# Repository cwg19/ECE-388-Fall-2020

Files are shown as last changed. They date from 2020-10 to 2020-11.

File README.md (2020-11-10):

# Function Generator
## UMassD ECE 388 Embedded System Design

### Project Scope
Simple Function gnerator
* produces sinusoid, square, and triangle waves
* Adjustable frequency up to 1MHz
* Adjustable gain between +/- ~10V
* Adjustable phase
* Rotary encoder w/ push button to select setting and change value
* Keypad to enter value
* LCD display

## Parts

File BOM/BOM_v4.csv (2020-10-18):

Qty | Value | Device | Package | Tolerance | Rating | Parts | Description | LCSC Price 1 | LCSC Price 10 | LCSC Pricee 100 | LCSC Price 1000 | LCSC PN | LCSC Link | Digikey Price | Digikey Link
3 | 6.2V | ZENER-DIODESOD80C | SOD80C | 2V | 6.2V 500mW 3uA @ 4V | D1, D2, D3 | Z-Diode |  |  | 0.15439 | 0.03613212 | C282536 | https://lcsc.com/product-detail/Zener-Diodes_Nexperia-BZV55-B6V2-115_C282536.html
1 | 10nF | C-EUC0805 | C0805 | 10% | 500V | C20 | CAPACITOR, European symbol |  |  | 0.16748 | 0.1233 | C309038 | https://lcsc.com/product-detail/Multilayer-Ceramic-Capacitors-MLCC-SMD-SMT_CCTC-TCC0805X7R103K501DTS_C309038.html
15 | 100nF | C-EUC0805 | C0805 | 10% | 250V | C1, C2, C3, C4, C5, C6, C7, C8, C9, C10, C11, C12, C13, C14, C21 | CAPACITOR, European symbol |  |  | 0.08029 | 0.183533 | C710458 | https://lcsc.com/product-detail/Multilayer-Ceramic-Capacitors-MLCC-SMD-SMT_HUI-JU-NM0805B104K251CEDN_C710458.html
1 | 1 | R-EU_R0805 | R0805 | 5% | 0.125W | R1 | RESISTOR, European symbol |  |  | 0.001894 | 0.001449 | C104066 | https://lcsc.com/product-detail/Chip-Resistor-Surface-Mount_1R-1R0-5_C104066.html
10 | 10k | R-EU_R0805 | R0805 | 1% | 0.125W | R2, R12, R13, R14, R15, R16, R17, R18, R19, R20 | RESISTOR, European symbol |  |  | 0.002477 | 0.001928 | C38522 | https://lcsc.com/product-detail/Chip-Resistor-Surface-Mount_UNI-ROYAL-Uniroyal-Elec-0805W8F1002T5E_C38522.html
2 | 10uF | C-EUC0805 | C0805 | 10% | 25V | C15, C16 | CAPACITOR, European symbol |  | 0.034545 | 0.029111 | 0.026285 | C40894 | https://lcsc.com/product-detail/Multilayer-Ceramic-Capacitors-MLCC-SMD-SMT_FH-Guangdong-Fenghua-Advanced-Tech-0805X106K250NT_C40894.html
1 | 16MHz | CRYSTALHC49UP | HC49UP | 20ppm | 20pF 30ohm | Q1 | CRYSTAL |  | 0.17467 | 0.129776 | 0.113286 | C259047 | https://lcsc.com/product-detail/SMD-Crystal-Resonators_ECEC-ZheJiang-E-ast-Crystal-Elec-C16000J119_C259047.html
1 | 1M | R-EU_R0805 | R0805 | 5% | 0.125W | R10 | RESISTOR, European symbol |  |  | 0.001495 | 0.001107 | C131391 | https://lcsc.com/product-detail/Chip-Resistor-Surface-Mount_FH-Guangdong-Fenghua-Advanced-Tech-RS-05K105JT_C131391.html
9 | 1k | R-EU_R0805 | R0805 | 5% | 0.125W | R3, R21, R22, R23, R24, R25, R26, R27, R30 | RESISTOR, European symbol |  |  | 0.001474 | 0.001095 | C25623 | https://lcsc.com/product-detail/Chip-Resistor-Surface-Mount_UNI-ROYAL-Uniroyal-Elec-0805W8J0102T5E_C25623.html
8 | 1.3k | R-EU_R0805 | R0805 | 1% | 0.125W | R4, R5, R6, R7, R8, R9, R31, R32 | RESISTOR, European symbol |  |  | 0.031326 | 0.022996 | C230658 | https://lcsc.com/product-detail/Chip-Resistor-Surface-Mount_PANASONIC-ERJ6ENF1300V_C230658.html
1 | 1uF | C-EUC0805 | C0805 | 10% | 50V | C17 | CAPACITOR, European symbol |  |  | 0.087535 | 0.2013519 | C282736 | https://lcsc.com/product-detail/Multilayer-Ceramic-Capacitors-MLCC-SMD-SMT_CCTC-TCC0805X7R105K500DTB_C282736.html
2 | 2.2uF | C-EUC0805 | C0805 | 10% | 25V | C18, C19 | CAPACITOR, European symbol |  |  | 0.083415 | 0.01916993 | C19110 | https://lcsc.com/product-detail/Multilayer-Ceramic-Capacitors-MLCC-SMD-SMT_SAMSUNG_CL21B225KAFNNNE_2-2uF-225-10-25V_C19110.html
2 | 22pF | C-EUC0805 | C0805 | 5% | 50V | C22, C23 | CAPACITOR, European symbol |  |  | 0.021236 | 0.02361 | C465168 | https://lcsc.com/product-detail/Multilayer-Ceramic-Capacitors-MLCC-SMD-SMT_Chinocera-HGC0805G0220J500NTGJ_C465168.html
1 | 25MHz | CRYSTALHC49UP | HC49UP | 30ppm | 20pF 50ohm | Q2 | CRYSTAL |  | 0.189734 | 0.14142 | 0.117488 | C111118 | https://lcsc.com/product-detail/SMD-Crystal-Resonators_TAE-Zhejiang-Abel-Elec-HC-49SM25MHz20pF30ppm_C111118.html
1 | 4.7uH | L-EUL0201 | L0201 | 20% | 800mA 312mohm | L1 | INDUCTOR, European symbol |  | 0.033768 | 0.0246 | 0.022917 | C63166 | https://lcsc.com/product-detail/Inductors-SMD_Sunlord-MPL2012S4R7MHT_C63166.html
1 | 68k | R-EU_R0805 | R0805 | 5% | 0.125W | R11 | RESISTOR, European symbol |  |  | 0.001395 | 0.001007 | C25641 | https://lcsc.com/product-detail/Chip-Resistor-Surface-Mount_UNI-ROYAL-Uniroyal-Elec-0805W8J0683T5E_C25641.html
1 |  | A1944-50 | A1944 |  |  | X1 | BNC CONNECTOR 50 Ohm |  |  |  |  |  |  | 11.76 | https://www.digikey.com/en/products/detail/amphenol-rf/112435/2628898
1 |  | AD9833 | MSOP10 |  |  | IC1 | LowPower Waveform Generator | 4.575 | 3.926667 | 3.808333 | 3.688333 | C9652 | https://lcsc.com/product-detail/Interface-Direct-Digital-Synthesis-DDS_Analog-Devices_AD9833BRMZ_Analog-Devices-ADI-LINEAR-AD9833BRMZ_C9652.html
1 |  | DCJ0202 | DCJ0202 |  |  | J1 | DC POWER JACK |  | 0.243966 | 0.177334 | 0.152834 | C111573 | https://lcsc.com/product-detail/AC-DC-Power-Plugs-Receptacles_SOFNG-DC005-T25_C111573.html
2 |  | LM318MX/NOPB | SOIC-8 |  |  | IC4, IC5 | OP AMP | 0.803333 | 0.581667 | 0.486617 | 0.46075 | C128749 | https://lcsc.com/product-detail/General-Purpose-Amplifiers_Texas-Instruments_LM318MX-NOPB_Texas-Instruments-Texas-Instruments-LM318MX-NOPB_C128749.html
1 |  | MAX9939AUB+ | 21-0061L |  |  | U2 | Programmable Gain Amplifier | 2.511667 | 2.16 | 2.031667 | 1.966667 | C143637 | https://lcsc.com/product-detail/Operational-Amplifiers_MAXIM_MAX9939AUB_MAX9939AUB_C143637.html
1 |  | MICROCHIP_ATMEGA328PB-AUMICROCHIP_ATMEGA328PB-AU_0_0 | MICROCHIP_ATMEGA328PB-AU_0 |  |  | U1 | ATmega328PB Summary Datasheet | 2.865 | 2.086667 | 1.8 | 1.705 | C194192 | https://lcsc.com/product-detail/ATMEL-AVR_Microchip-Tech-ATMEGA328PB-AN_C194192.html
1 |  | TLV61048DBVR | SOT95P280X145-6N |  |  | U3 |  |  |  |  |  |  |  | 1.12 | https://www.digikey.com/en/products/detail/texas-instruments/TLV61048DBVR/10715594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

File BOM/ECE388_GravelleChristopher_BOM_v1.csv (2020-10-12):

Qty | Value | Device | Package | Parts | Description | AVAILABILITY | BUILT_BY | CENTROID_NOT_SPECIFIED | DATASHEET | DESCRIPTION.1 | DIGIKEY_DESCRIPTION | DIGIKEY_PART_NUMBER | LEAD_FREE | MANUFACTURER_PART_NUMBER | MF | MFG_PACKAGE_IDENT | LCSC_PART_NUMBER | LCSC_MANUFACTURER | LCSC_MF_PART_NUMBER | OC_FARNELL | OC_NEWARK | PACKAGE.1 | POPULARITY | PREFIX | DIGIKEY_PRICE | LCSC_PRICE | SOURCELIBRARY | SPICEPREFIX | TEMPERATURE_RANGE_HIGH | TEMPERATURE_RANGE_LOW | VENDOR | VOLTAGE | Column1
1 | 16MHz | CRYSTALHC49UP | HC49UP | Q1 | CRYSTAL | 1000 | ILSI |  |  | CANT FIND ON LCSC | ±30ppm Crystal 18pF HC-49/US | 2780-HC49USM-FF3F18-16.000MHZTR-ND |  | HC49USM-FF3F18-16.000MHZ | ILSI |  |  |  |  |  |  |  |  |  | 0.29
1 | 25MHz | CRYSTALHC49UP | HC49UP | Q2 | CRYSTAL | 1000 | ILSI |  |  | CANT FIND ON LCSC | CRYSTAL 25.0000MHZ 18PF SMD | 2780-HC49USM-FF5F18-25.000MHZCT-ND |  | HC49USM-FF5F18-25.000MHZ | ILSI |  |  |  |  | unknown | unknown |  | 19 |  | 0.29
4 |  | JP1E | JP1 | JP2, JP3, JP4, JP5 | JUMPER |  |  |  |  |  |  |  |  |  |  |  |  |  |  |  |  |  | 61
1 |  | JP3QE | JP3Q | JP1 | JUMPER |  |  |  |  |  |  |  |  |  |  |  |  |  |  |  |  |  | 0
1 | .1pF | C-EUC0805 | C0805 | C19 | CAPACITOR, European symbol |  |  |  |  |  |  |  |  |  |  |  |  |  |  |  |  |  | 88 |  |  |  |  | C
1 | 0 | R-EU_R0805 | R0805 | R16 | RESISTOR, European symbol |  |  |  |  |  |  |  |  |  |  |  |  |  |  |  |  |  | 86 |  |  |  |  | R
1 | 0.1uF | C-EUC0805 | C0805 | C1 | CAPACITOR, European symbol |  |  |  |  |  |  |  |  |  |  |  |  |  |  |  |  |  | 88 |  |  |  |  | C
2 | 0.33uF | C-EUC0805 | C0805 | C2, C4 | CAPACITOR, European symbol |  |  |  |  |  |  |  |  |  |  |  |  |  |  |  |  |  | 88 |  |  |  |  | C
4 | 100 | R-EU_R0805 | R0805 | R10, R11, R12, R13 | RESISTOR, European symbol |  |  |  |  |  |  |  |  |  |  |  |  |  |  |  |  |  | 86 |  |  |  |  | R
6 | 100nF | C-EUC0805 | C0805 | C5, C6, C9, C10, C11, C15 | CAPACITOR, European symbol |  |  |  |  |  |  |  |  |  |  |  |  |  |  |  |  |  | 88 |  |  |  |  | C
1 | 10M | R-EU_R0805 | R0805 | R15 | RESISTOR, European symbol |  |  |  |  |  |  |  |  |  |  |  |  |  |  |  |  |  | 86 |  |  |  |  | R
4 | 10k | R-EU_R0805 | R0805 | R2, R3, R6, R8 | RESISTOR, European symbol |  |  |  |  |  |  |  |  |  |  |  |  |  |  |  |  |  | 86 |  |  |  |  | R
1 | 10nF | C-EUC0805 | C0805 | C8 | CAPACITOR, European symbol |  |  |  |  |  |  |  |  |  |  |  |  |  |  |  |  |  | 88 |  |  |  |  | C
2 | 10uF | C-EUC0805 | C0805 | C7, C17 | CAPACITOR, European symbol |  |  |  |  |  |  |  |  |  |  |  |  |  |  |  |  |  | 88 |  |  |  |  | C
2 | 1k | R-EU_R0805 | R0805 | R1, R14 | RESISTOR, European symbol |  |  |  |  |  |  |  |  |  |  |  |  |  |  |  |  |  | 86 |  |  |  |  | R
1 | 1mF | C-EUC0805 | C0805 | C12 | CAPACITOR, European symbol |  |  |  |  |  |  |  |  |  |  |  |  |  |  |  |  |  | 88 |  |  |  |  | C
2 | 1uF | C-EUC0805 | C0805 | C3, C18 | CAPACITOR, European symbol |  |  |  |  |  |  |  |  |  |  |  |  |  |  |  |  |  | 88 |  |  |  |  | C
2 | 200 | R-EU_R0805 | R0805 | R9, R18 | RESISTOR, European symbol |  |  |  |  |  |  |  |  |  |  |  |  |  |  |  |  |  | 86 |  |  |  |  | R
2 | 22pF | C-EUC0805 | C0805 | C13, C14 | CAPACITOR, European symbol |  |  |  |  |  |  |  |  |  |  |  |  |  |  |  |  |  | 88 |  |  |  |  | C
3 | 330 | R-EU_R0805 | R0805 | R17, R19, R20 | RESISTOR, European symbol |  |  |  |  |  |  |  |  |  |  |  |  |  |  |  |  |  | 86 |  |  |  |  | R
3 | 4k7 | R-EU_R0805 | R0805 | R4, R5, R7 | RESISTOR, European symbol |  |  |  |  |  |  |  |  |  |  |  |  |  |  |  |  |  | 86 |  |  |  |  | R
1 | 7805DT | 7805DT | TO252 | IC3 | Positive VOLTAGE REGULATOR | 1126 | Texas Instruments |  | https://www.ti.com/lit/ds/symlink/lm340.pdf?HQS=TI-null-null-digikeymode-df-pf-null-wwe&ts=1602214386688 |  | IC REG LINEAR 5V 1.5A SOT223-4 | 296-44517-1-ND |  | LM7805MP/NOPB | Texas Instruments |  | C725350 | HGSEMI | LM7805CS/TR |  |  |  | 0 |  | 1.32 | 0.188967
1 | A1944-50 | A1944-50 | A1944 | X1 | BNC CONNECTOR 50 Ohm |  |  |  |  |  |  |  |  |  |  |  |  |  |  | unknown | unknown |  | 1
1 | AD9833 | AD9833 | MSOP10 | IC1 | LowPower Waveform Generator | 318 | Analog Devices |  | https://datasheet.lcsc.com/szlcsc/1809042016_Analog-Devices-AD9833BRMZ-REEL7_C9652.pdf | Direct Digital Synthesis IC 10 b 25MHz 28 b Tuning 10-MSOP | 10 b 25MHz 28 b 2.3V ~ 5.5V MSOP-10 Interface - Direct Digital Synthesis (DDS) RoHS | AD9833BRMZ-ND |  | AD9833BRMZ | Analog Devices |  | C9652 | Analog Devices | AD9833BRMZ-REEL7 |  |  | MSOP-10 Analog Devices |  |  | 10.04 | 4.575
1 | DCJ0202 | DCJ0202 | DCJ0202 | J1 | DC POWER JACK | 1663 | Conec |  | https://media.digikey.com/pdf/Data%20Sheets/Conec%20PDFs/33DCJ-0202-A.pdf |  | Power Barrel Connector Jack - Through Hole, Right Angle | 626-1968-ND |  | 33DCJ-0202-A | Conec |  |  |  |  | unknown | unknown |  | 17 |  | 0.73
1 | MAX9939AUB+ | MAX9939AUB+ | 21-0061L | U2 |  | 1516 | Maxim Integrated |  | https://datasheets.maximintegrated.com/en/ds/MAX9939.pdf |  | Programmable Gain Amplifier Circuit Differential 10-uMAX | MAX9939AUB+-ND |  | max9939aub+ | Maxim Integrated |  | C143637 | Maxim Integrated | MAX9939AUB+ |  |  |  |  |  | 2.35 | 2.511667 | Maxim_2009-12-17_3b |  |  |  | Maxim Integrated Products
1 | ATMEGA328PB | ATMEGA328PB-AU | ATMEGA328PB-AU | U1 | ATmega328PB Summary Datasheet | 4879 | Microchip Technology | No | http://ww1.microchip.com/downloads/en/DeviceDoc/40001907A.pdf |  | IC MCU 8BIT 32KB FLASH 32TQFP | ATMEGA328PB-AU-ND | yes | ATMEGA328PB-AU | Microchip | 32A | C132230 | Microchip | ATMEGA328PB-AU |  |  | TQFP32 |  | U | 1.34 | 1.806667 |  |  | +85Â°C | -40Â°C |  | 5.5V
1 | PCF8574T | PCF8574T | SO16W | IC2 | I2C-Bus Remote 8-bit I/O expander | 14951 | NXP USA Inc. |  | https://www.nxp.com/docs/en/data-sheet/PCF8574_PCF8574A.pdf |  | I/O Expander 8 I2C 16-SO | 568-1077-1-ND - Cut Tape (CT) |  | PCF8574T/3,518 | NXP USA Inc. |  | C398075 | HGSEMI | PCF8574T | 1201255 | 70R6870 |  | 3 |  | 1.44 | 0.718333
3 | U57X32 | U57X32 | U57X32 | D1, D2, D4 | LED |  |  |  |  |  |  |  |  |  |  |  |  |  |  |  |  |  | 0

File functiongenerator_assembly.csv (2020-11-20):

UUID | Designator | Qty | Self Sourced | Value | Device | Package | Parts | Description
R-2019-44 | C | 1 |  | 0.01uF | C-EUC0805 | C0805 | C20 | CAPACITOR, European symbol
R-2019-01 | C | 14 |  | 0.1uF | C-EUC0805 | C0805 | C1, C5, C6, C11, C14, C21, C28, C29, C31, C32, C33, C34, C35, C40 | CAPACITOR, European symbol
R-2019-06 | R | 1 |  | 1 | R-EU_R0805 | R0805 | R1 | RESISTOR, European symbol
R-2019-36 | R | 7 |  | 10k | R-EU_R0805 | R0805 | R8, R9, R14, R15, R24, R32, R44 | RESISTOR, European symbol
R-2019-21 | C | 5 |  | 10uF | C-EUC0805 | C0805 | C2, C3, C15, C16, C24 | CAPACITOR, European symbol
R-2019-08 | XTAL | 1 |  | 16MHz | CRYSTALHC49UP | HC49UP | Q3 | CRYSTAL
R-2020-02 | R | 1 |  | 1M | R-EU_R0805 | R0805 | R10 | RESISTOR, European symbol
R-2019-05 | R | 8 |  | 1k | R-EU_R0805 | R0805 | R28, R29, R37, R38, R39, R41, R42, R43 | RESISTOR, European symbol
R-2019-51 | R | 2 |  | 1k3 | R-EU_R0805 | R0805 | R6, R7 | RESISTOR, European symbol
R-2020-01 | C | 1 |  | 1uF | C-EUC0805 | C0805 | C17 | CAPACITOR, European symbol
R-2020-01 | C | 2 |  | 2.2uF | C-EUC0805 | C0805 | C18, C19 | CAPACITOR, European symbol
R-2019-43 | C | 2 |  | 22pF | C-EUC0805 | C0805 | C36, C37 | CAPACITOR, European symbol
R-2019-02 | R | 1 |  | 330 | R-EU_R0805 | R0805 | R40 | RESISTOR, European symbol
L-2020-23 | L | 1 |  | 4.7uH | L-USL0805 | C0805 | L1 | INDUCTOR, American symbol
R-2020-06 | R | 1 |  | 68k | R-EU_R0805 | R0805 | R11 | RESISTOR, European symbol
L-2020-33 | U | 1 |  | AD9833 | AD9833 | MSOP10 | IC1 | LowPower Waveform Generator
L-2020-40 | U | 2 |  | LM318D | LM318D | SOIC8 | IC4, IC5 | FAST GENERAL-PURPOSE OPERATIONAL AMPLIFIER
R-2019-61 | D | 3 |  | MBR0520LT | MBR0520LT | SMC | D4, D5, D6 | SCHOTTKY BARRIER RECTIFIER
L-2020-48 | U | 1 |  | ATMEGA328PB | ATMEGA328PB | MICROCHIP_ATMEGA328PB-AU_0 | U2 | ATmega328PB Summary Datasheet
L-2020-58 | U | 1 |  | TLV1117-33IDCY | TLV1117-33IDCY | SOT230P700X180-4N | U1 | 3.3v regulator
L-2020-50 | U | 1 |  | TLV61048DBVR | TLV61048DBVR | SOT95P280X145-6N | U3 | Boost Converter

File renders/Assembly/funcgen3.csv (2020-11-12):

Qty | Value | Device | Package | Parts | Description | AVAILABILITY | CENTROID_NOT_SPECIFIED | DATASHEET | DESCRIPTION | DIGIKEY_DESCRIPTION | DIGIKEY_PART_NUMBER | LEAD_FREE | MF | MFG_PACKAGE_IDENT | MOUSER_PART_NUMBER | MP | MPN | OC_FARNELL | OC_NEWARK | PACKAGE | POPULARITY | PREFIX | PRICE | PURCHASE-URL | ROHS | SPICEPREFIX | TEMPERATURE_RANGE_HIGH | TEMPERATURE_RANGE_LOW | VOLTAGE
5 |  | JP1E | JP1 | JP1, JP5, JP7, LCD/I2C1, LCD_POW | JUMPER |  |  |  |  |  |  |  |  |  |  |  |  |  |  |  | 61
3 |  | JP2E | JP2 | JP6, POT1K, POT50K | JUMPER |  |  |  |  |  |  |  |  |  |  |  |  |  |  |  | 34
1 |  | JP4QE | JP4Q | JP8 | JUMPER |  |  |  |  |  |  |  |  |  |  |  |  |  |  |  | 0
1 | 0.01uF | C-EUC0805 | C0805 | C20 | CAPACITOR, European symbol |  |  |  |  |  |  |  |  |  |  |  |  |  |  |  | 88 |  |  |  |  | C
14 | 0.1uF | C-EUC0805 | C0805 | C1, C5, C6, C11, C14, C21, C28, C29, C31, C32, C33, C34, C35, C40 | CAPACITOR, European symbol |  |  |  |  |  |  |  |  |  |  |  |  |  |  |  | 88 |  |  |  |  | C
1 | 1 | R-EU_R0805 | R0805 | R1 | RESISTOR, European symbol |  |  |  |  |  |  |  |  |  |  |  |  |  |  |  | 86 |  |  |  |  | R
7 | 10k | R-EU_R0805 | R0805 | R8, R9, R14, R15, R24, R32, R44 | RESISTOR, European symbol |  |  |  |  |  |  |  |  |  |  |  |  |  |  |  | 86 |  |  |  |  | R
5 | 10uF | C-EUC0805 | C0805 | C2, C3, C15, C16, C24 | CAPACITOR, European symbol |  |  |  |  |  |  |  |  |  |  |  |  |  |  |  | 88 |  |  |  |  | C
1 | 16MHz | CRYSTALHC49UP | HC49UP | Q3 | CRYSTAL |  |  |  |  |  |  |  |  |  |  |  |  | unknown | unknown |  | 19
1 | 1M | R-EU_R0805 | R0805 | R10 | RESISTOR, European symbol |  |  |  |  |  |  |  |  |  |  |  |  |  |  |  | 86 |  |  |  |  | R
8 | 1k | R-EU_R0805 | R0805 | R28, R29, R37, R38, R39, R41, R42, R43 | RESISTOR, European symbol |  |  |  |  |  |  |  |  |  |  |  |  |  |  |  | 86 |  |  |  |  | R
2 | 1k3 | R-EU_R0805 | R0805 | R6, R7 | RESISTOR, European symbol |  |  |  |  |  |  |  |  |  |  |  |  |  |  |  | 86 |  |  |  |  | R
1 | 1uF | C-EUC0805 | C0805 | C17 | CAPACITOR, European symbol |  |  |  |  |  |  |  |  |  |  |  |  |  |  |  | 88 |  |  |  |  | C
2 | 2.2uF | C-EUC0805 | C0805 | C18, C19 | CAPACITOR, European symbol |  |  |  |  |  |  |  |  |  |  |  |  |  |  |  | 88 |  |  |  |  | C
2 | 22pF | C-EUC0805 | C0805 | C36, C37 | CAPACITOR, European symbol |  |  |  |  |  |  |  |  |  |  |  |  |  |  |  | 88 |  |  |  |  | C
1 | 330 | R-EU_R0805 | R0805 | R40 | RESISTOR, European symbol |  |  |  |  |  |  |  |  |  |  |  |  |  |  |  | 86 |  |  |  |  | R
1 | 4.7uH | L-USL0805 | C0805 | L1 | INDUCTOR, American symbol
1 | 68k | R-EU_R0805 | R0805 | R11 | RESISTOR, European symbol |  |  |  |  |  |  |  |  |  |  |  |  |  |  |  | 86 |  |  |  |  | R
1 | AD9833 | AD9833 | MSOP10 | IC1 | LowPower Waveform Generator | Bad |  |  | Direct Digital Synthesis IC 10 b 25MHz 28 b Tuning 10-MSOP |  |  |  | Analog Devices |  |  | AD9833 |  |  |  | MSOP-10 Analog Devices |  |  | None
1 | ASFL1 | ASFL1 | ASF | Q2 | CRYSTAL CLOCK OSCILLATORS |  |  |  |  |  |  |  | Abracon Corporation |  |  |  | ASFL1-125.000MHZ-EC-T | 1838931 | 19M1882 |  | 0
1 | AVR-ISP | AVR-ISP | AVR-ISP | U$2 | Check prices | Bad |  |  | Emulators / Simulators AVR USB IN CIRCUIT EMUL/PRGMR ISP |  |  |  | Gravitech |  |  | AVR-ISP |  |  |  | None |  |  | None
3 | FIDUCIAL | FIDUCIAL | FIDUCIAL_1MM | U$1, U$3, U$4 | For use by pick and place machines to calibrate the vision/machine, 1mm
2 | LM318D | LM318D | SOIC8 | IC4, IC5 | FAST GENERAL-PURPOSE OPERATIONAL AMPLIFIER |  |  |  |  |  |  |  |  |  |  |  |  |  |  |  | 0
3 | MBR0520LT | MBR0520LT | SOD123 | D4, D5, D6 | SCHOTTKY BARRIER RECTIFIER |  |  |  |  |  |  |  |  |  |  |  |  |  |  |  | 2
1 | MICROCHIP_ATMEGA328PB-AUMICROCHIP_ATMEGA328PB-AU_0_0 | MICROCHIP_ATMEGA328PB-AUMICROCHIP_ATMEGA328PB-AU_0_0 | MICROCHIP_ATMEGA328PB-AU_0 | U2 | ATmega328PB Summary Datasheet |  | No | http://ww1.microchip.com/downloads/en/DeviceDoc/40001907A.pdf |  | IC MCU 8BIT 32KB FLASH 32TQFP | ATMEGA328PB-AU-ND | yes | Microchip | 32A | 556-ATMEGA328PB-AU |  | ATmega328PB-AU |  |  | TQFP32 |  | U |  |  | yes |  | +85°C | -40°C | 5.5V
1 | TLV1117-33IDCY | TLV1117-33IDCY | SOT230P700X180-4N | U1 | Check prices | Good |  |  | 800-mA, 15-V, linear voltage regulator 4-SOT-223 -40 to 125 |  |  |  | Texas Instruments |  |  | TLV1117-33IDCY |  |  |  | SOT-223-4 Texas Instruments |  |  | None | https://pricing.snapeda.com/search/part/TLV1117-33IDCY/?ref=eda
1 | TLV61048DBVR | TLV61048DBVR | SOT95P280X145-6N | U3 | Check prices | Warning |  |  | 14-V output voltage non-synchronous boost converter in SOT-23 package 6-SOT-23 -40 to 125 |  |  |  | Texas Instruments |  |  | TLV61048DBVR |  |  |  | SOT-23-6 Texas Instruments |  |  | None | https://pricing.snapeda.com/search/part/TLV61048DBVR/?ref=eda

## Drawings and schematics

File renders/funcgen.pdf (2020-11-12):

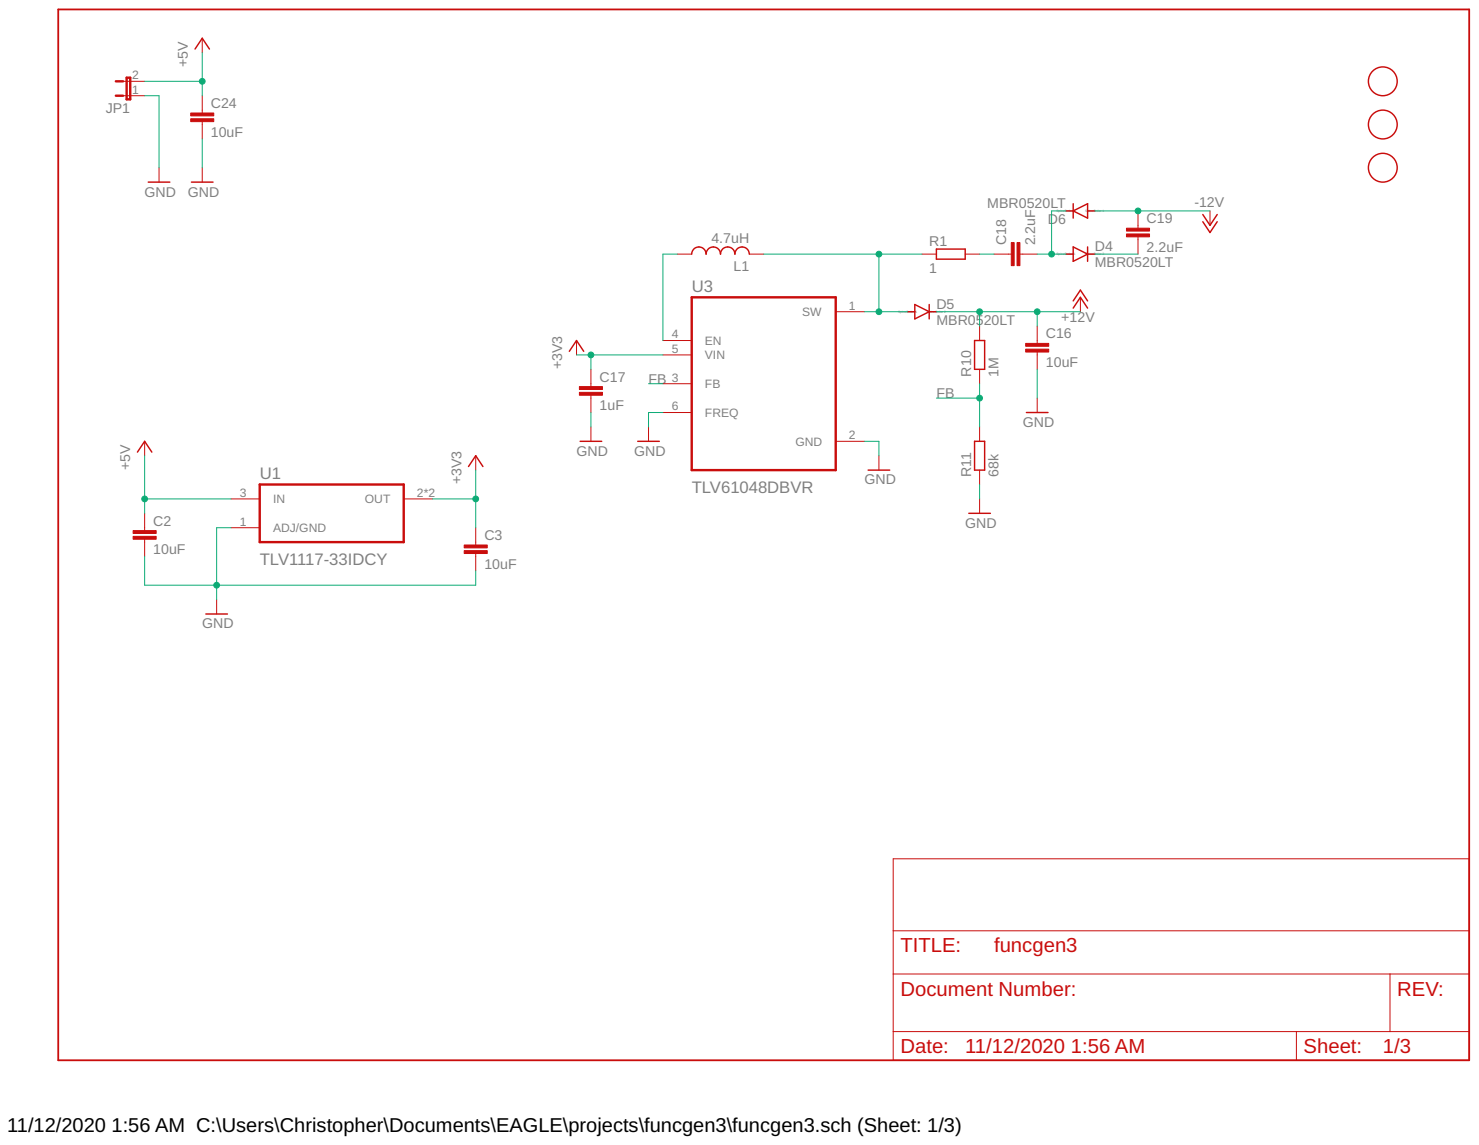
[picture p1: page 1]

Document Number: | REV:

Date: 11/12/2020 1:56 AM | Sheet: 1/3

11/12/2020 1:56 AM C:\Users\Christopher\Documents\EAGLE\projects\funcgen3\funcgen3.sch (Sheet: 1/3)

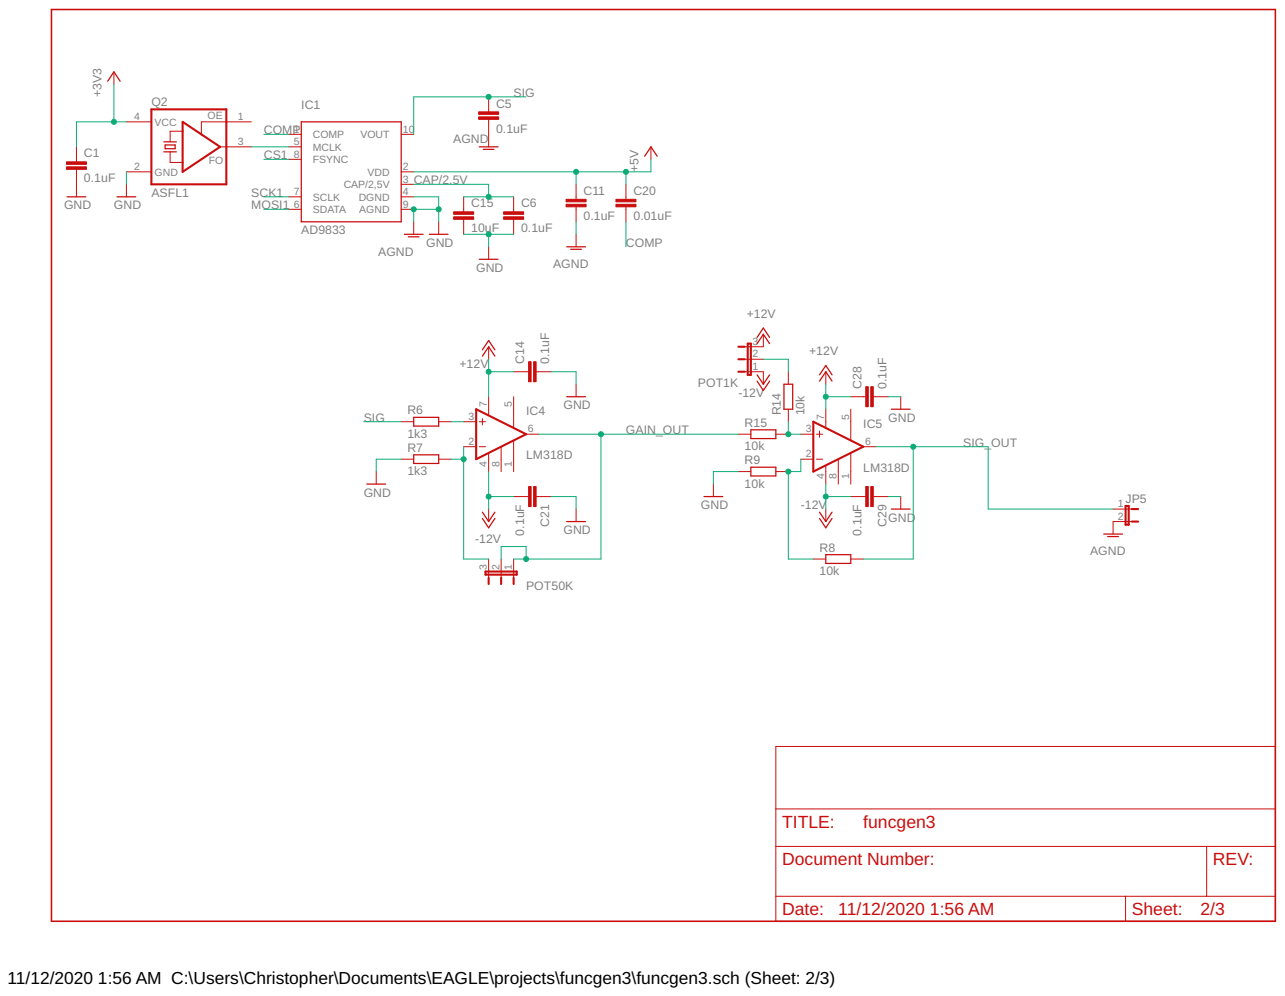
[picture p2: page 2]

CAP/2.5V AGND

Document Number: | REV:

Date: 11/12/2020 1:56 AM | Sheet: 2/3

11/12/2020 1:56 AM C:\Users\Christopher\Documents\EAGLE\projects\funcgen3\funcgen3.sch (Sheet: 2/3)

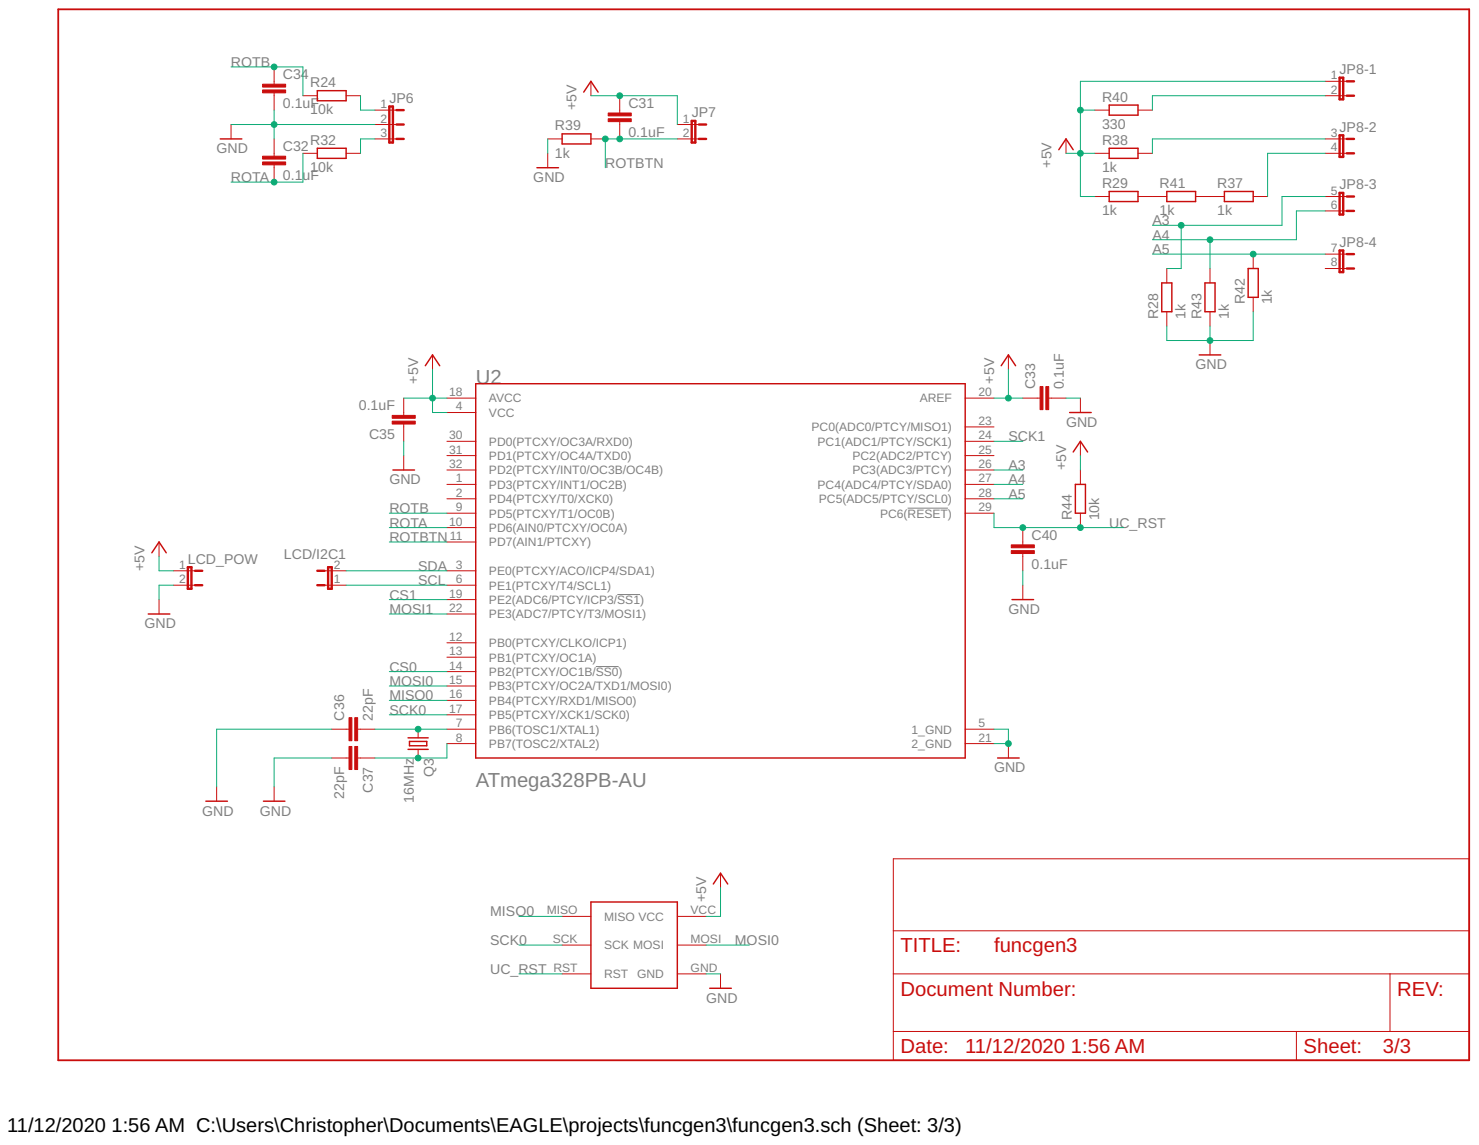
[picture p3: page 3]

11/12/2020 1:56 AM C:\Users\Christopher\Documents\EAGLE\projects\funcgen3\funcgen3.sch (Sheet: 3/3)

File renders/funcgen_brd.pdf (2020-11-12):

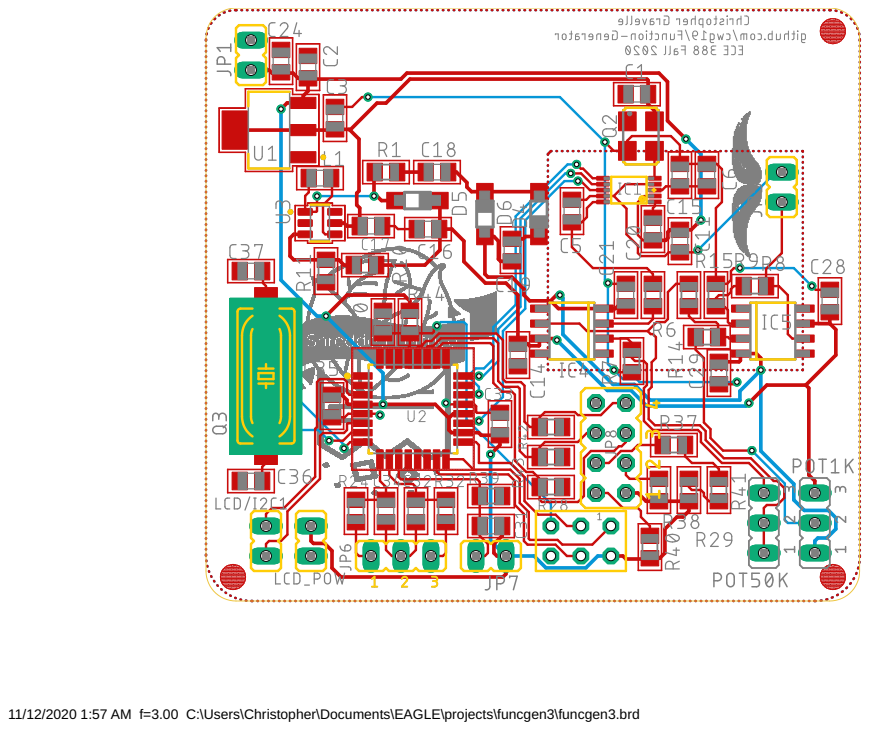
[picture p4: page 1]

11/12/2020 1:57 AM f=3.00 C:\Users\Christopher\Documents\EAGLE\projects\funcgen3\funcgen3.brd

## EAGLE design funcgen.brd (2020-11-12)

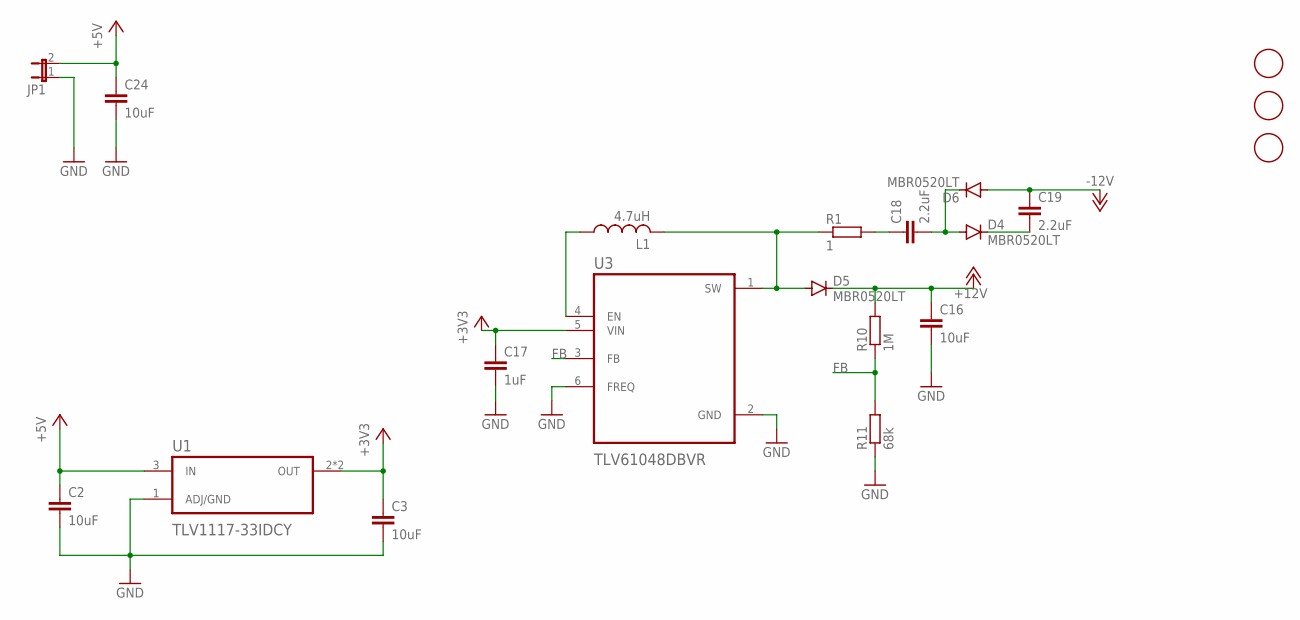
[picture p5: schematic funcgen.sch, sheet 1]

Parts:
C2, C3, C16, C24: 10uF; C0805
C17: 1uF; C0805
C18, C19: 2.2uF; C0805
D4, D5, D6: MBR0520LT; SOD123
JP1: JP1E; JP1
L1: 4.7uH; C0805
R1: 1; R0805
R10: 1M; R0805
R11: 68k; R0805
U1: TLV1117-33IDCY; SOT230P700X180-4N
U3: TLV61048DBVR; SOT95P280X145-6N
U$1, U$3, U$4: FIDUCIAL; FIDUCIAL_1MM

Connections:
+3V3: C3.1, C17.1, U1.2 (OUT), U1.4 (OUT), U3.5 (VIN); also elsewhere on the board
+5V: C2.1, C24.1, JP1.2, U1.3 (IN); also elsewhere on the board
+12V: C16.1, D5.C, R10.2; also elsewhere on the board
-12V: C19.1, D6.A; also elsewhere on the board
FB: R10.1, R11.2, U3.3 (FB)
GND: C2.2, C3.2, C16.2, C17.2, C24.2, JP1.1, R11.1, U1.1 (ADJ/GND), U3.2 (GND), U3.6 (FREQ); also elsewhere on the board
unnamed: L1.1, U3.4 (EN)
unnamed: D5.A, L1.2, R1.1, U3.1 (SW)
unnamed: C18.1, R1.2
unnamed: C18.2, D4.A, D6.C
unnamed: C19.2, D4.C

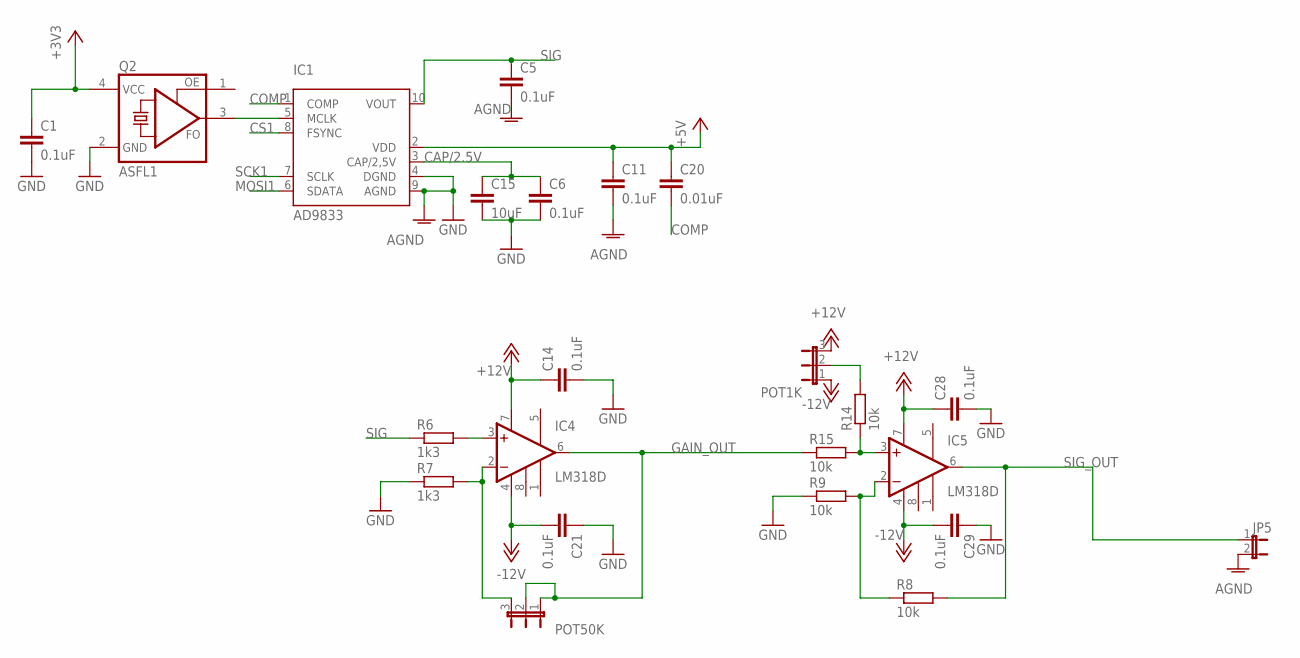
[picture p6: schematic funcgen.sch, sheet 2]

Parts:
C1, C5, C6, C11, C14, C21, C28, C29: 0.1uF; C0805
C15: 10uF; C0805
C20: 0.01uF; C0805
IC1: AD9833; MSOP10
IC4, IC5: LM318D; SOIC8
JP5: JP1E; JP1
POT1K, POT50K: JP2E; JP2
Q2: ASFL1; ASF
R6, R7: 1k3; R0805
R8, R9, R14, R15: 10k; R0805

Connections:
+3V3: C1.1, Q2.4 (VCC); also elsewhere on the board
+5V: C11.1, C20.1, IC1.2 (VDD); also elsewhere on the board
+12V: C14.1, C28.1, IC4.7 (V+), IC5.7 (V+), POT1K.3; also elsewhere on the board
-12V: C21.2, C29.2, IC4.4 (V-), IC5.4 (V-), POT1K.1; also elsewhere on the board
AGND: C5.2, C11.2, IC1.4 (DGND), IC1.9 (AGND), JP5.2
CAP/2.5V: C6.1, C15.1, IC1.3 (CAP/2,5V)
COMP: C20.2, IC1.1 (COMP)
CS1: IC1.8 (FSYNC); also elsewhere on the board
GAIN_OUT: IC4.6 (OUT), POT50K.1, POT50K.2, R15.1
GND: C1.2, C6.2, C14.2, C15.2, C21.1, C28.2, C29.1, Q2.2 (GND), R7.1, R9.1; also elsewhere on the board
MOSI1: IC1.6 (SDATA); also elsewhere on the board
unnamed: IC1.5 (MCLK), Q2.3 (FO)
unnamed: IC4.3 (+IN), R6.2
unnamed: IC4.2 (-IN), POT50K.3, R7.2
unnamed: IC5.3 (+IN), R14.1, R15.2
unnamed: POT1K.2, R14.2
unnamed: IC5.2 (-IN), R8.1, R9.2
SCK1: IC1.7 (SCLK); also elsewhere on the board
SIG: C5.1, IC1.10 (VOUT), R6.1
SIG_OUT: IC5.6 (OUT), JP5.1, R8.2

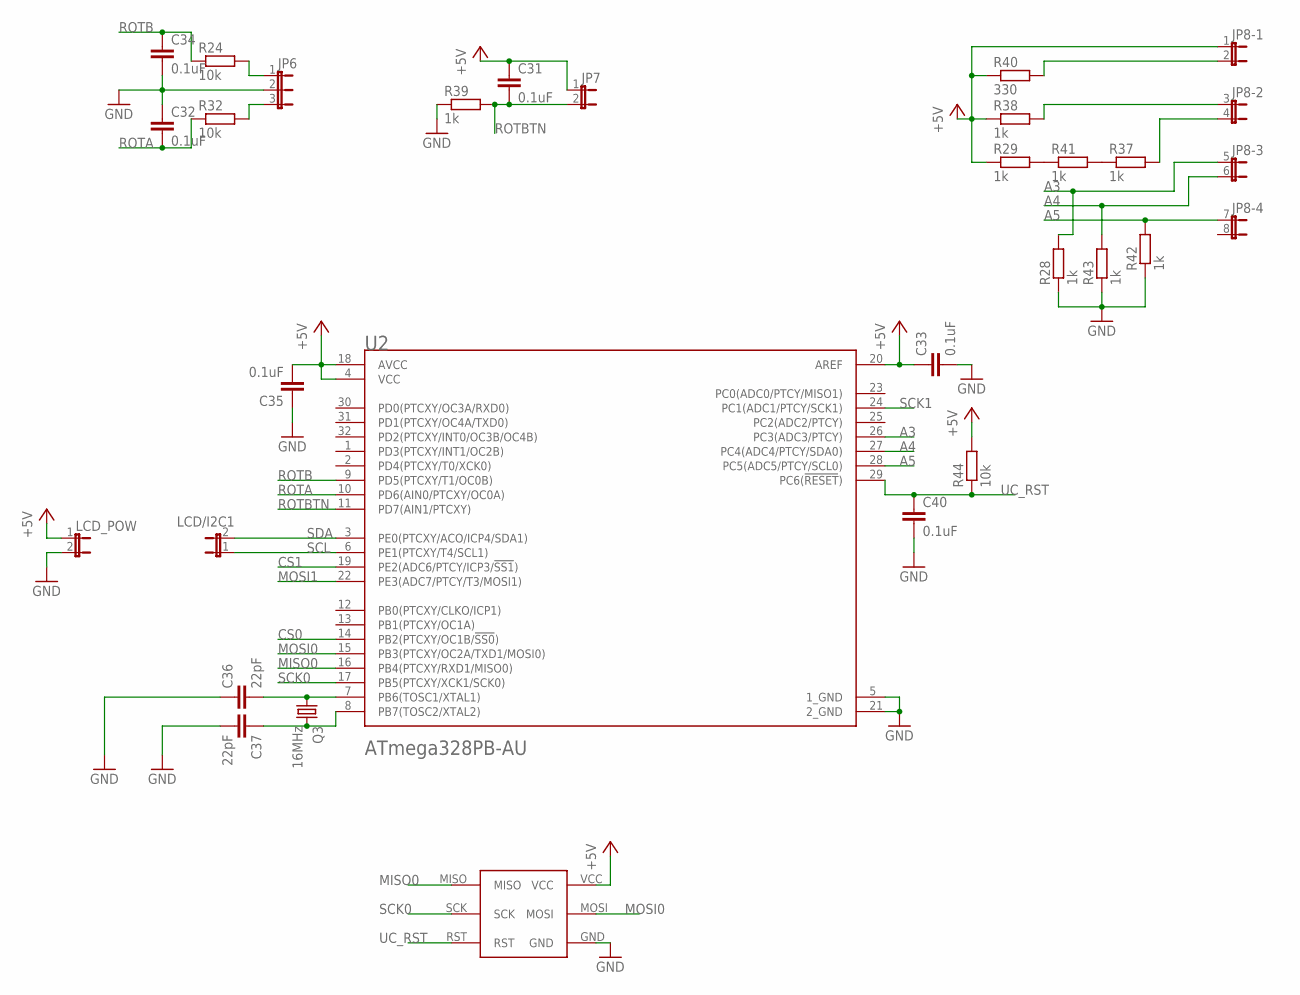
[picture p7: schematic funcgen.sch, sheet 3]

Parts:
C31, C32, C33, C34, C35, C40: 0.1uF; C0805
C36, C37: 22pF; C0805
JP6: JP2E; JP2
JP7: JP1E; JP1
JP8: JP4QE; JP4Q
LCD/I2C1: JP1E; JP1
LCD_POW: JP1E; JP1
Q3: 16MHz; HC49UP
R24, R32, R44: 10k; R0805
R28, R29, R37, R38, R39, R41, R42, R43: 1k; R0805
R40: 330; R0805
U2: MICROCHIP_ATMEGA328PB-AUMICROCHIP_ATMEGA328PB-AU_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; MICROCHIP_ATMEGA328PB-AU_0
U$2: AVR-ISP

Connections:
+5V: C31.1, C33.1, C35.2, JP7.1, JP8.1, LCD_POW.1, R29.1, R38.1, R40.1, R44.2, U2.4 (VCC), U2.18 (AVCC), U2.20 (AREF), U$2.VCC; also elsewhere on the board
A3: JP8.5 (1), R28.2, U2.26 (PC3(ADC3/PTCY))
A4: JP8.6 (2), R43.2, U2.27 (PC4(ADC4/PTCY/SDA0))
A5: JP8.7 (1), R42.2, U2.28 (PC5(ADC5/PTCY/SCL0))
CS0: U2.14 (PB2(PTCXY/OC1B/!SS0!))
CS1: U2.19 (PE2(ADC6/PTCY/ICP3/!SS1!)); also elsewhere on the board
GND: C32.1, C33.2, C34.2, C35.1, C36.1, C37.2, C40.2, JP6.2, LCD_POW.2, R28.1, R39.1, R42.1, R43.1, U2.5 (1_GND), U2.21 (2_GND), U$2.GND; also elsewhere on the board
MISO0: U2.16 (PB4(PTCXY/RXD1/MISO0)), U$2.MISO
MOSI0: U2.15 (PB3(PTCXY/OC2A/TXD1/MOSI0)), U$2.MOSI
MOSI1: U2.22 (PE3(ADC7/PTCY/T3/MOSI1)); also elsewhere on the board
unnamed: JP6.1, R24.2
unnamed: JP6.3, R32.2
unnamed: C36.2, Q3.1, U2.7 (PB6(TOSC1/XTAL1))
unnamed: C37.1, Q3.2, U2.8 (PB7(TOSC2/XTAL2))
unnamed: R37.1, R41.2
unnamed: R29.2, R41.1
unnamed: JP8.2, R40.2
unnamed: JP8.3 (1), R38.2
unnamed: JP8.4 (2), R37.2
ROTA: C32.2, R32.1, U2.10 (PD6(AIN0/PTCXY/OC0A))
ROTB: C34.1, R24.1, U2.9 (PD5(PTCXY/T1/OC0B))
ROTBTN: C31.2, JP7.2, R39.2, U2.11 (PD7(AIN1/PTCXY))
SCK0: U2.17 (PB5(PTCXY/XCK1/SCK0)), U$2.SCK
SCK1: U2.24 (PC1(ADC1/PTCY/SCK1)); also elsewhere on the board
SCL: LCD/I2C1.1, U2.6 (PE1(PTCXY/T4/SCL1))
SDA: LCD/I2C1.2, U2.3 (PE0(PTCXY/ACO/ICP4/SDA1))
UC_RST: C40.1, R44.1, U2.29 (PC6(!RESET!)), U$2.RST

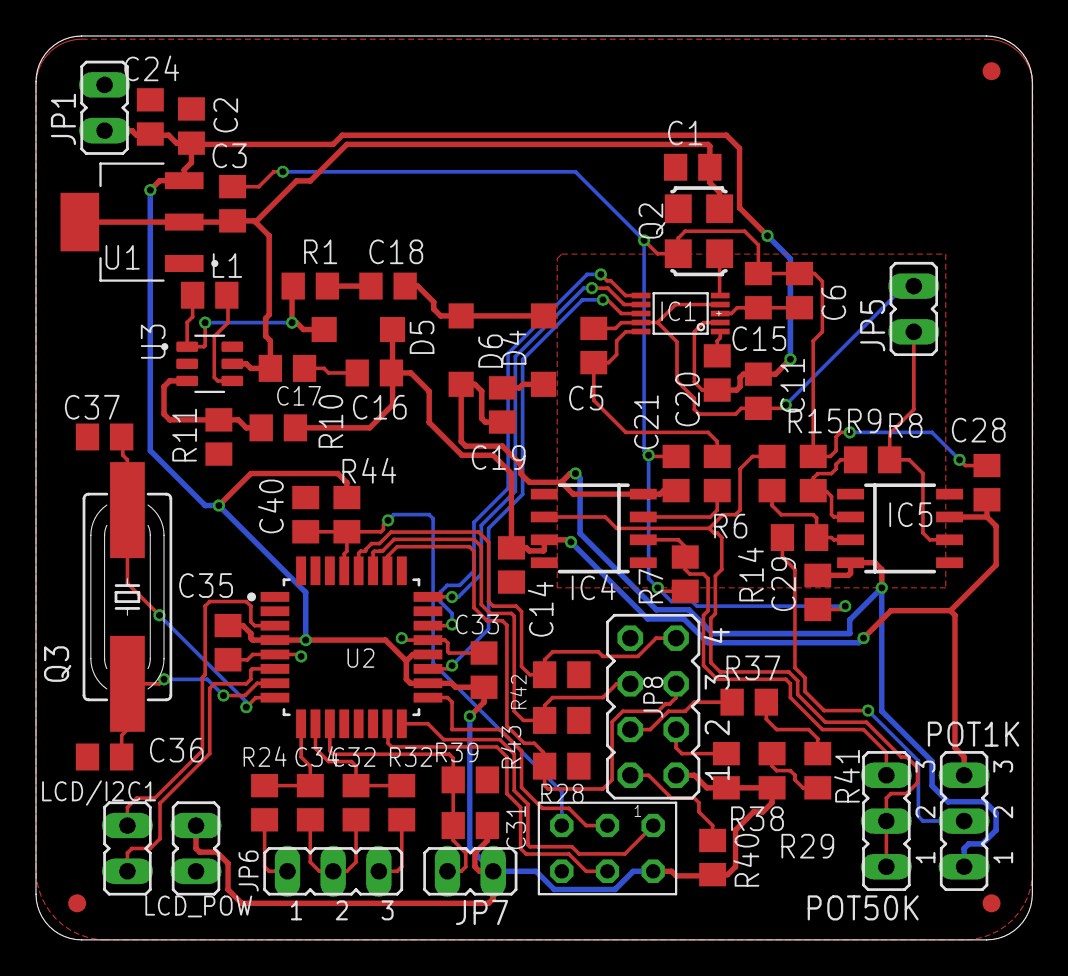
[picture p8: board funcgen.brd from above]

Board: 2 copper layers, 55.4 x 50.2 mm, 71 parts (0 on the bottom side), 47 nets.

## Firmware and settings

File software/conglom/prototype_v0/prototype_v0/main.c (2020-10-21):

/*
 * prototype_v0.c
 *
 * Created: 10/21/2020 12:02:42 PM
 * Author : Christopher
 */ 

#include <avr/io.h>
#define F_CPU 16000000UL
#include <util/delay.h>
#include "userinterface.h" 
#include "AD9833.h"

/* modes
	1. signal mode display 
	2. voltage display
	3. frequency display
	4. phase display
	In each mode display the mode and the appro
*/

extern volatile uint8_t mode;
extern volatile uint8_t modeLast;
extern volatile uint8_t setVal;
extern volatile uint8_t aQuiescent;
extern volatile uint8_t aState;
extern volatile uint8_t rotation;

extern volatile const char* labels[4];
extern volatile const char* units[3];
extern volatile const char* signals[4];

extern volatile uint32_t frequency;
extern volatile uint16_t phase;
extern volatile int8_t voltage;
extern volatile uint8_t signal;

extern volatile uint16_t controlReg;



int main(void) {
	uint8_t signalLast = signal;
	uint32_t freqLast = frequency;
	uint16_t phaseLast = phase;
	aQuiescent = ROTARY_PIN & (1<<ROTARY_A);
	uiInit();
	SPI_init();
	AD9833_init();
    while (1) {
		setRotaryStatus();
		if (setVal) {
			switch(mode) {
				case MODE_SIGNAL:
					if (rotation == CLOCKWISE)
						signal = (signal+1)&3;
					else if (rotation == COUNTERCLOCKWISE)
						signal = (signal-1)&3;
					break;
				case MODE_VOLTAGE:
					if ((rotation == CLOCKWISE) && (voltage < V_MAX)) {
						voltage++;
					}
					else if ((rotation == COUNTERCLOCKWISE) && (voltage > V_MIN)) {
						voltage--;
					}
					break;
				case MODE_FREQUENCY:
					if ((rotation == CLOCKWISE) && (frequency < FREQ_MAX))
						frequency++;
					else if ((rotation == COUNTERCLOCKWISE) && (frequency > FREQ_MIN))
						frequency--;
					break;
				case MODE_PHASE:
					if ((rotation == CLOCKWISE) && (phase < PHASE_MAX))
						phase++;
					else if ((rotation == COUNTERCLOCKWISE) && (phase > PHASE_MIN))
						phase--;
					break;
			}
		}
		else {
			/* DOES THIS GO HERE */
			/* Goal is to let user cycle through choices
			   and only change the signal output when the button
			   was pressed */
			if (signal != signalLast)
				setSignalOut();
			if (frequency != freqLast)
				freqChange(frequency,0);
			if (phase != phaseLast)
				phaseChange(phase,0);
			if (rotation == CLOCKWISE)
				getNextMode();
			else if (rotation == COUNTERCLOCKWISE)
				getPreviousMode();
		}
		// display mode and value with units
		if (rotation != NO_ROTATION)
			displayRefresh();
		signalLast = signal;
		freqLast = frequency;
		phaseLast = phase;
	}
}

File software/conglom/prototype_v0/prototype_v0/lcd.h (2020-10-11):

#ifndef LCD_H
#define LCD_H
/*************************************************************************
 Title	:   C include file for the HD44780U LCD library (lcd.c)
 Author:    Peter Fleury <pfleury@gmx.ch>  http://tinyurl.com/peterfleury
 File:	    $Id: lcd.h,v 1.14.2.4 2015/01/20 17:16:07 peter Exp $
 Software:  AVR-GCC 4.x
 Hardware:  any AVR device, memory mapped mode only for AVR with 
            memory mapped interface (AT90S8515/ATmega8515/ATmega128)
***************************************************************************/

/**
 @mainpage
 Collection of libraries for AVR-GCC
 @author Peter Fleury pfleury@gmx.ch http://tinyurl.com/peterfleury
 @copyright (C) 2015 Peter Fleury, GNU General Public License Version 3
 
 @file
 @defgroup pfleury_lcd LCD library <lcd.h>
 @code #include <lcd.h> @endcode
 
 @brief Basic routines for interfacing a HD44780U-based character LCD display

 LCD character displays can be found in many devices, like espresso machines, laser printers. 
 The Hitachi HD44780 controller and its compatible controllers like Samsung KS0066U have become an industry standard for these types of displays. 
 
 This library allows easy interfacing with a HD44780 compatible display and can be
 operated in memory mapped mode (LCD_IO_MODE defined as 0 in the include file lcd.h.) or in 
 4-bit IO port mode (LCD_IO_MODE defined as 1). 8-bit IO port mode is not supported.

 Memory mapped mode is compatible with old Kanda STK200 starter kit, but also supports
 generation of R/W signal through A8 address line.

 @see The chapter <a href=" http://homepage.hispeed.ch/peterfleury/avr-lcd44780.html" target="_blank">Interfacing a HD44780 Based LCD to an AVR</a>
      on my home page, which shows example circuits how to connect an LCD to an AVR controller. 

 @author Peter Fleury pfleury@gmx.ch http://tinyurl.com/peterfleury
 
 @version   2.0
 
 @copyright (C) 2015 Peter Fleury, GNU General Public License Version 3
  
*/

#include <inttypes.h>
#include <avr/pgmspace.h>

#if (__GNUC__ * 100 + __GNUC_MINOR__) < 405
#error "This library requires AVR-GCC 4.5 or later, update to newer AVR-GCC compiler !"
#endif


/**@{*/

/*
 * LCD and target specific definitions below can be defined in a separate include file with name lcd_definitions.h instead modifying this file 
 * by adding -D_LCD_DEFINITIONS_FILE to the CDEFS section in the Makefile
 * All definitions added to the file lcd_definitions.h will override the default definitions from lcd.h
 */
#ifdef _LCD_DEFINITIONS_FILE
#include "lcd_definitions.h"
#endif


/**
 * @name  Definition for LCD controller type
 * Use 0 for HD44780 controller, change to 1 for displays with KS0073 controller.
 */
#ifndef LCD_CONTROLLER_KS0073 
#define LCD_CONTROLLER_KS0073 0  /**< Use 0 for HD44780 controller, 1 for KS0073 controller */
#endif

/** 
 * @name  Definitions for Display Size 
 * Change these definitions to adapt setting to your display
 *
 * These definitions can be defined in a separate include file \b lcd_definitions.h instead modifying this file by 
 * adding -D_LCD_DEFINITIONS_FILE to the CDEFS section in the Makefile.
 * All definitions added to the file lcd_definitions.h will override the default definitions from lcd.h
 *
 */
#ifndef LCD_LINES
#define LCD_LINES           4     /**< number of visible lines of the display */
#endif
#ifndef LCD_DISP_LENGTH
#define LCD_DISP_LENGTH    20     /**< visibles characters per line of the display */
#endif
#ifndef LCD_LINE_LENGTH
#define LCD_LINE_LENGTH  0x40     /**< internal line length of the display    */
#endif
#ifndef LCD_START_LINE1
#define LCD_START_LINE1  0x00     /**< DDRAM address of first char of line 1 */
#endif
#ifndef LCD_START_LINE2
#define LCD_START_LINE2  0x40     /**< DDRAM address of first char of line 2 */
#endif
#ifndef LCD_START_LINE3
#define LCD_START_LINE3  0x14     /**< DDRAM address of first char of line 3 */
#endif
#ifndef LCD_START_LINE4
#define LCD_START_LINE4  0x54     /**< DDRAM address of first char of line 4 */
#endif
#ifndef LCD_WRAP_LINES
#define LCD_WRAP_LINES      0     /**< 0: no wrap, 1: wrap at end of visibile line */
#endif


/**
 * @name Definitions for 4-bit IO mode
 *
 * The four LCD data lines and the three control lines RS, RW, E can be on the 
 * same port or on different ports. 
 * Change LCD_RS_PORT, LCD_RW_PORT, LCD_E_PORT if you want the control lines on
 * different ports. 
 *
 * Normally the four data lines should be mapped to bit 0..3 on one port, but it
 * is possible to connect these data lines in different order or even on different
 * ports by adapting the LCD_DATAx_PORT and LCD_DATAx_PIN definitions.
 *
 * Adjust these definitions to your target.\n 
 * These definitions can be defined in a separate include file \b lcd_definitions.h instead modifying this file by 
 * adding \b -D_LCD_DEFINITIONS_FILE to the \b CDEFS section in the Makefile.
 * All definitions added to the file lcd_definitions.h will override the default definitions from lcd.h
 *  
 */
#define LCD_IO_MODE      1            /**< 0: memory mapped mode, 1: IO port mode */

#if LCD_IO_MODE

#ifndef LCD_PORT
#define LCD_PORT         PORTA        /**< port for the LCD lines   */
#endif
#ifndef LCD_DATA0_PORT
#define LCD_DATA0_PORT   LCD_PORT     /**< port for 4bit data bit 0 */
#endif
#ifndef LCD_DATA1_PORT
#define LCD_DATA1_PORT   LCD_PORT     /**< port for 4bit data bit 1 */
#endif
#ifndef LCD_DATA2_PORT
#define LCD_DATA2_PORT   LCD_PORT     /**< port for 4bit data bit 2 */
#endif
#ifndef LCD_DATA3_PORT
#define LCD_DATA3_PORT   LCD_PORT     /**< port for 4bit data bit 3 */
#endif
#ifndef LCD_DATA0_PIN
#define LCD_DATA0_PIN    0            /**< pin for 4bit data bit 0  */
#endif
#ifndef LCD_DATA1_PIN
#define LCD_DATA1_PIN    1            /**< pin for 4bit data bit 1  */
#endif
#ifndef LCD_DATA2_PIN
#define LCD_DATA2_PIN    2            /**< pin for 4bit data bit 2  */
#endif
#ifndef LCD_DATA3_PIN
#define LCD_DATA3_PIN    3            /**< pin for 4bit data bit 3  */
#endif
#ifndef LCD_RS_PORT
#define LCD_RS_PORT      LCD_PORT     /**< port for RS line         */
#endif
#ifndef LCD_RS_PIN
#define LCD_RS_PIN       4            /**< pin  for RS line         */
#endif
#ifndef LCD_RW_PORT
#define LCD_RW_PORT      LCD_PORT     /**< port for RW line         */
#endif
#ifndef LCD_RW_PIN
#define LCD_RW_PIN       5            /**< pin  for RW line         */
#endif
#ifndef LCD_E_PORT
#define LCD_E_PORT       LCD_PORT     /**< port for Enable line     */
#endif
#ifndef LCD_E_PIN
#define LCD_E_PIN        6            /**< pin  for Enable line     */
#endif
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

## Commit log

2020-10-11 Bill of Materials
    Revised Bill of Materials submission with information on parts from LCSC and digikey depending on availability.
    I left resistors and capacitors blank except for the component value because we are all supposed to be using the 0805 components. I did not fill out LEDs because I do not need any particular LEDs. Co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
    [ECE388_GravelleChristopher_BOM_v1.xlsx]
2020-10-12 Updating UI solution
    Rotary encoder interfacing is successful. Have yet to separate functionality into header and implementation files for lcd and rotary encoder functionality. The main program of this project is a test,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
2020-10-12 Functional user Interface program
    UI code with 4x20 LCD and I2C backpack. Works well despite sometimes skipping modes when rotating encoder and sometimes missing button pushes. I tried incorporating a timer to check the push button at a set interval as well as an external interrupt, however this caused the LCD to turn on and off at regular intervals. I could not figure out why, so I scrapped that idea and just went with the regular polling as I had been doing. Modularized my program slightly by moving macros, globals and functions into header and implementation files for the rotary encoder and the user interface as a whole. The next step is to interface with the AD9833 signal generator chip.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
    [main.c, rotary.h, userinterface.c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]
2020-10-12 .csv BOM
    [ECE388_GravelleChristopher_BOM_v1.csv]
2020-10-13 Create BOM\
2020-10-13 Bill of materials folder
    sdfljnsdlfnsdf
2020-10-13 bill of materials
    [ECE388_GravelleChristopher_BOM_v1.csv, ECE388_GravelleChristopher_BOM_v1.xlsx]
2020-10-17 BOM iteration 2 the sequel
    [BOM_v2.csv, BOM_v2.xlsx]
2020-10-17 Modularized AD9833 Header and Implementation
    Refined the .h and .c file for AD9833 for my purposes. CURRENTLY UNTESTED. Need to test this solution with oscilloscope / logic analyzer when I have lab time on Wednesday. The solution builds, but who knows what it actually does. Had stuff working in lab last week so hopefully we didn't bust it up too much. Ideally, this can be integrated with the user interface. Next step is to implement signal amplification to the picture. If I use a strictly analog amplifier, presenting a voltage reading on the display might be more of a challenge. With the Programmable gain amplifier (PGA) it is probably a more straightforward equation based on register settin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
    [AD9833.c, AD9833.h, main.c]
2020-10-18 BOM v3: the BOMbest BOM to Date
    Here we go again
    [BOM_v3.csv, BOM_v3.xlsx]
2020-10-18 BOM again
    idk
    [BOM_v4.csv, BOM_v4.xlsx]
2020-10-21 Integrating AD9833 and UI
    Integrating AD99833 signal generator with user interface code. UNTESTED. This will probably do something I just don't know what or how well. It wasn't too much additional stuffs to the UI, just triggering the AD9833 functions when a change has been made by the user.
    [AD9833.c, AD9833.h, lcd.h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]
2020-11-03 Schematic and Board pics
    Images of first-cut schematic and board layout with and without ratsnest view.
2020-11-03 Uploading CAM for 1st cut board
    1st cut board design CAMOutput files. The dimensions of my board are too large and that is the first thing I need to change. There were 2 warning on my schematic which were related to AGND being connected to GND at one point and from a pin being left NC. The rest are warnings which I don't think are concerning, so I approved them all. For the board layout, I have 8 errors which I approved because I don't really have a choice and I hope it is okay. The AD9833 signal generator chip I am using to generate the waveforms is very small. and the pads are very close together. The error is because the pads apparently violate the minimum spacing for the DRCs. PLEASE tel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
    [copper_bottom.gbr, copper_top.gbr, drill_1_16.xln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]
2020-11-08 Eagle schematic and board directory
    Keep Schematic and Board under version control
2020-11-08 Eagle board and schematic files
    [funcgen1.brd, funcgen1.sch]
2020-11-09 Revised and Updated Schematic and Board
    Changed schematic to multiple sheets with better organization. Board layout is redone entirely. Surface area is nearly cut in half from first design.
    ISSUES: 1) need to verify / find the proper DC jack connector.
    2) need an 0805 inductor package. I believe I left enough space for it, but for now the footprint is entirely incorrect
    [funcgen.brd, funcgen.sch]
2020-11-09 Uploading Schematic Image
    Schematic Printed to PDF. Multiple sheets and improved organization
2020-11-09 Upload Revised Board Images
    PCB Layout Images with and without ratsnest view
2020-11-09 Gerber and Assembly File Upload
    [PnP_funcgen3_front.csv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]
2020-11-09 Just the Gerbers
    [funcgen3.GBL, funcgen3.GBO, funcgen3.GBP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]
2020-11-12 Eagle Schematic and Board Upload
    Current Board and Schematic
    [funcgen.brd, funcgen.sch]
2020-11-12 Re-upload board and schematic
    [funcgen.brd]
2020-11-12 Updated Gerber and Assembly FIles
    [PnP_funcgen3_front.csv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]
2020-11-12 Updated Board and Schematic
    Updated Board and Schematic with SMA Schottky diodes and ISP pin 1 marking
    [funcgen.brd, funcgen.sch]
2020-11-12 Updated Board and Schematic Gerbs and stuffs
    Updated images for schematic and layout. SMA schottky diodes placed; NOTE: the Schottky diode symbol on the schematic looks like a normal diode, however the description claims it is a Schottky barrie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
    [PnP_funcgen3_front.csv, funcgen3.csv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]
2020-11-20 assembly BOM
    [functiongenerator_assembly.csv]
